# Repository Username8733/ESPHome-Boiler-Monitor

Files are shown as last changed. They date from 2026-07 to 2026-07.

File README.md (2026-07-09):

# ESPHome Boiler Monitor

Optisk pannovervakare for Home Assistant / ESPHome.

## Nya funktionsbilder

Se `docs/components/README.md` och `images/functions/`.

Varje delkrets har egen bild med exakt vilka komponentben som kopplas vart.

## GPIO

| Funktion | GPIO |
|---|---:|
| Fototransistor ADC | GPIO34 |
| Summer via 2N7000 | GPIO18 |
| Rod LED | GPIO19 |
| Gron LED | GPIO21 |
| Tyst-knapp | GPIO22 |

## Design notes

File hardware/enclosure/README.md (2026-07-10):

# Enclosure STL export

Generated from the two OpenSCAD files currently in the public repository.

## Files

- `hardware/enclosure/stl/boiler_alert_case.stl`
- `hardware/enclosure/stl/boiler_monitor_case.stl`

Each STL contains:

- Base enclosure: 100 × 60 × 30 mm
- Wall thickness: 2 mm
- Separate lid positioned 10 mm above the base in Y, matching the SCAD layout
- Lid holes:
  - Red LED: 5 mm
  - Green LED: 5 mm
  - Buzzer: 12 mm
  - Mute button: 7 mm

Triangle counts:

- boiler_alert_case.stl: 23748
- boiler_monitor_case.stl: 23748

The two SCAD files are geometrically identical except for comments.

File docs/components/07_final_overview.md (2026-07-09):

# 07 - Slutlig översikt

Schematiskt helhetsdiagram över alla funktioner tillsammans.

Bygg helst en funktion i taget med de separata funktionsbilderna.

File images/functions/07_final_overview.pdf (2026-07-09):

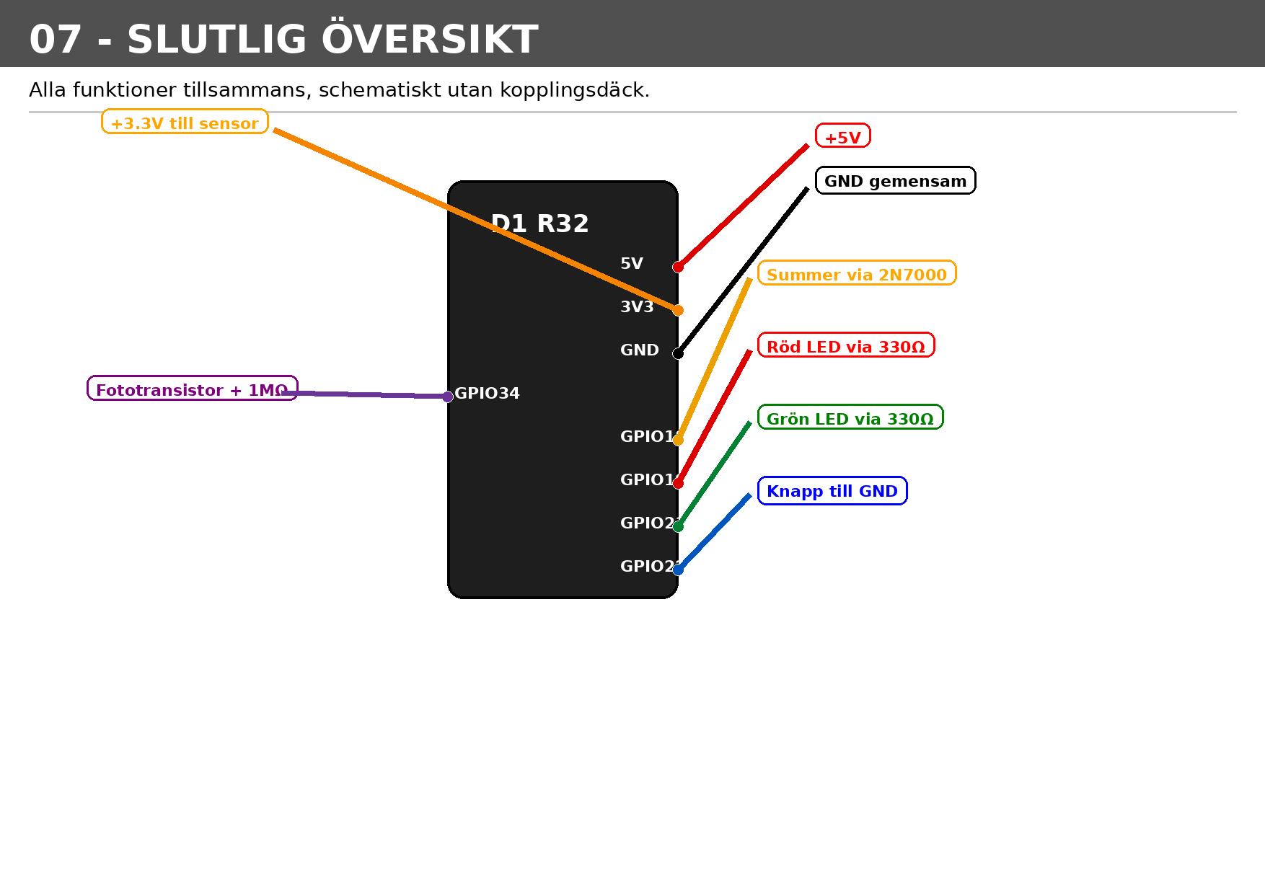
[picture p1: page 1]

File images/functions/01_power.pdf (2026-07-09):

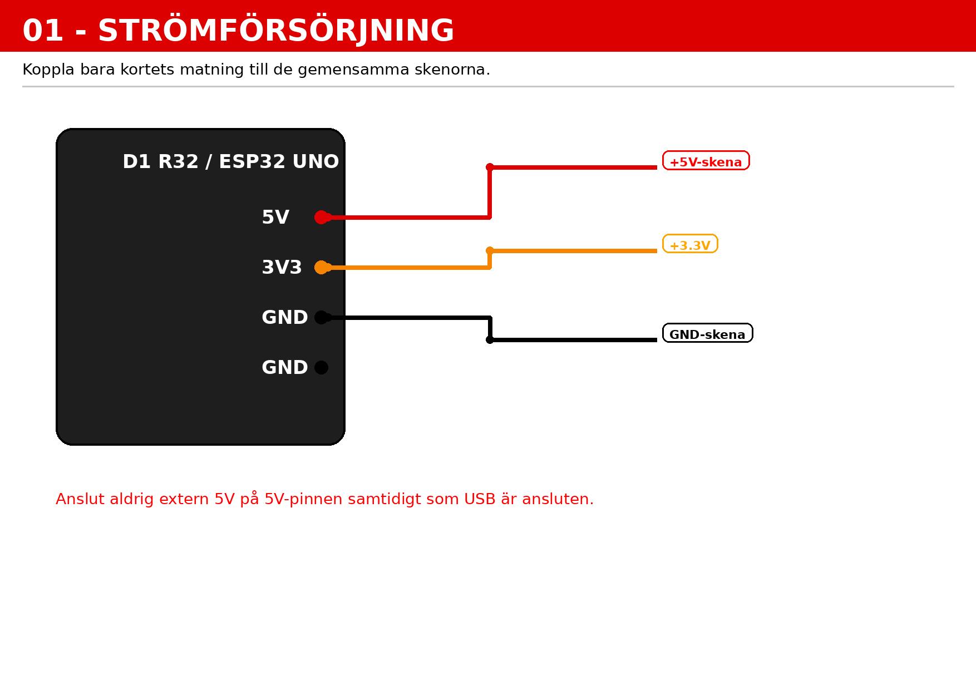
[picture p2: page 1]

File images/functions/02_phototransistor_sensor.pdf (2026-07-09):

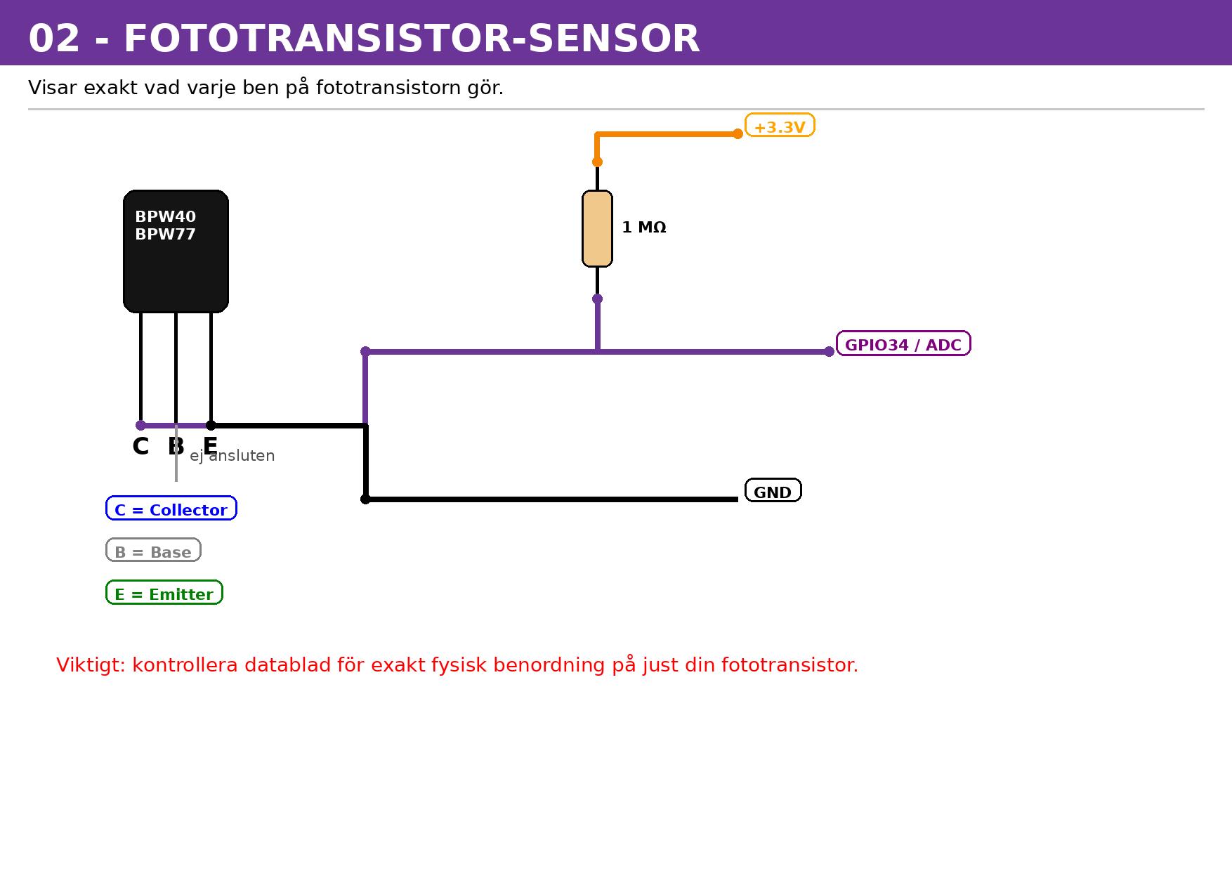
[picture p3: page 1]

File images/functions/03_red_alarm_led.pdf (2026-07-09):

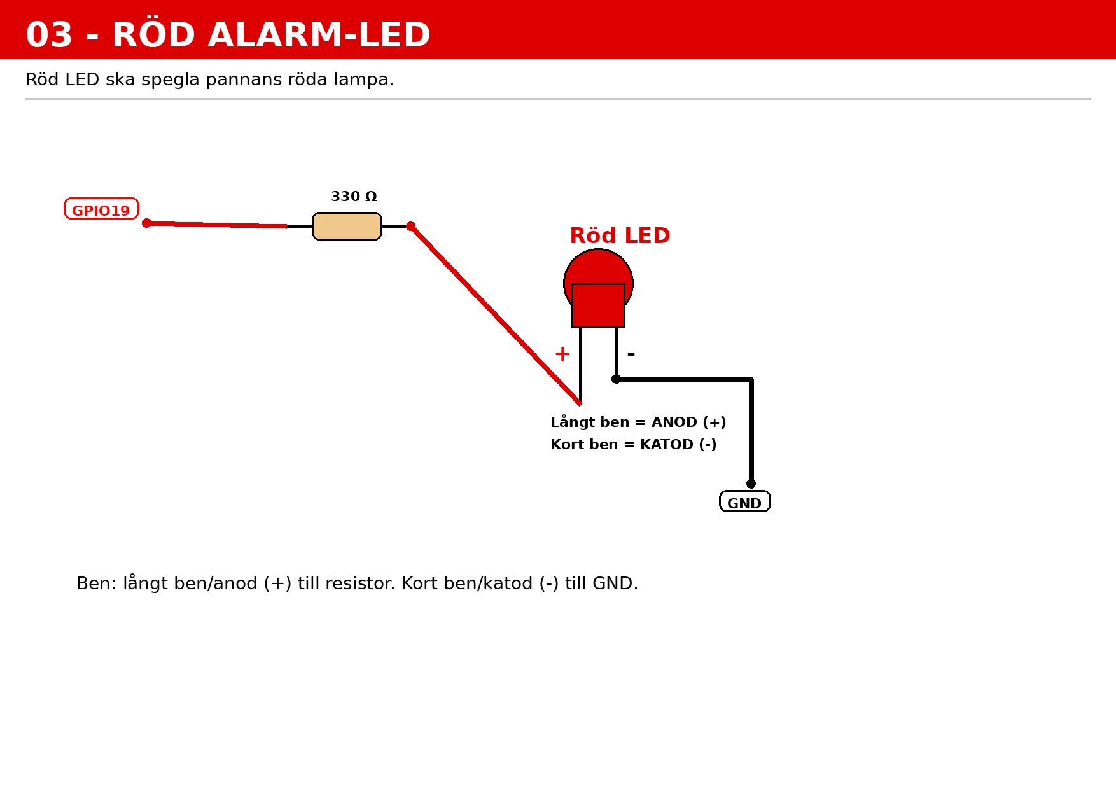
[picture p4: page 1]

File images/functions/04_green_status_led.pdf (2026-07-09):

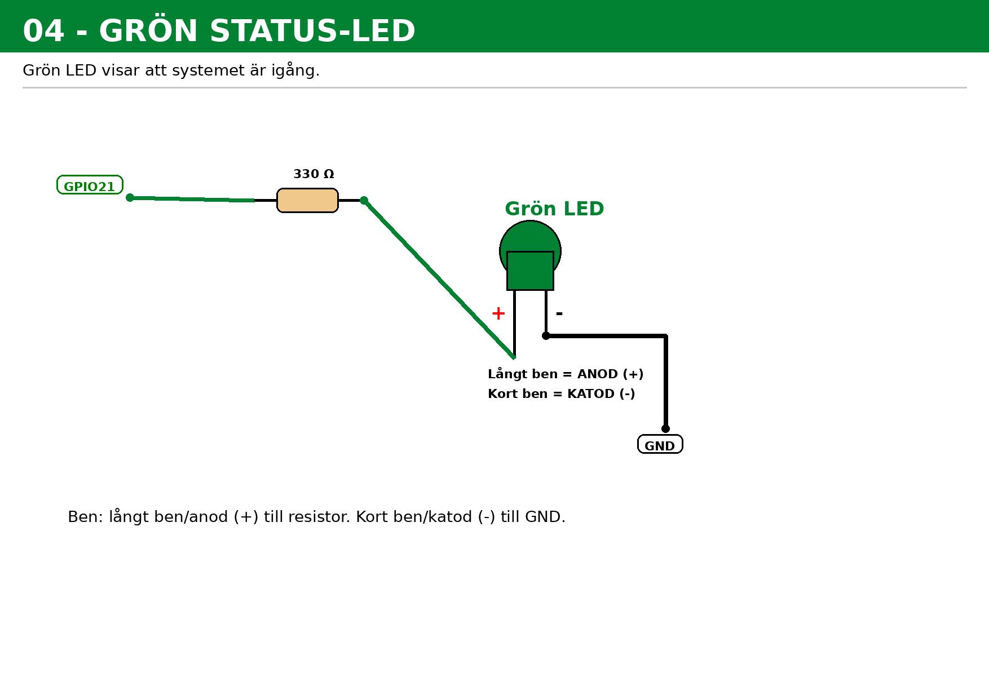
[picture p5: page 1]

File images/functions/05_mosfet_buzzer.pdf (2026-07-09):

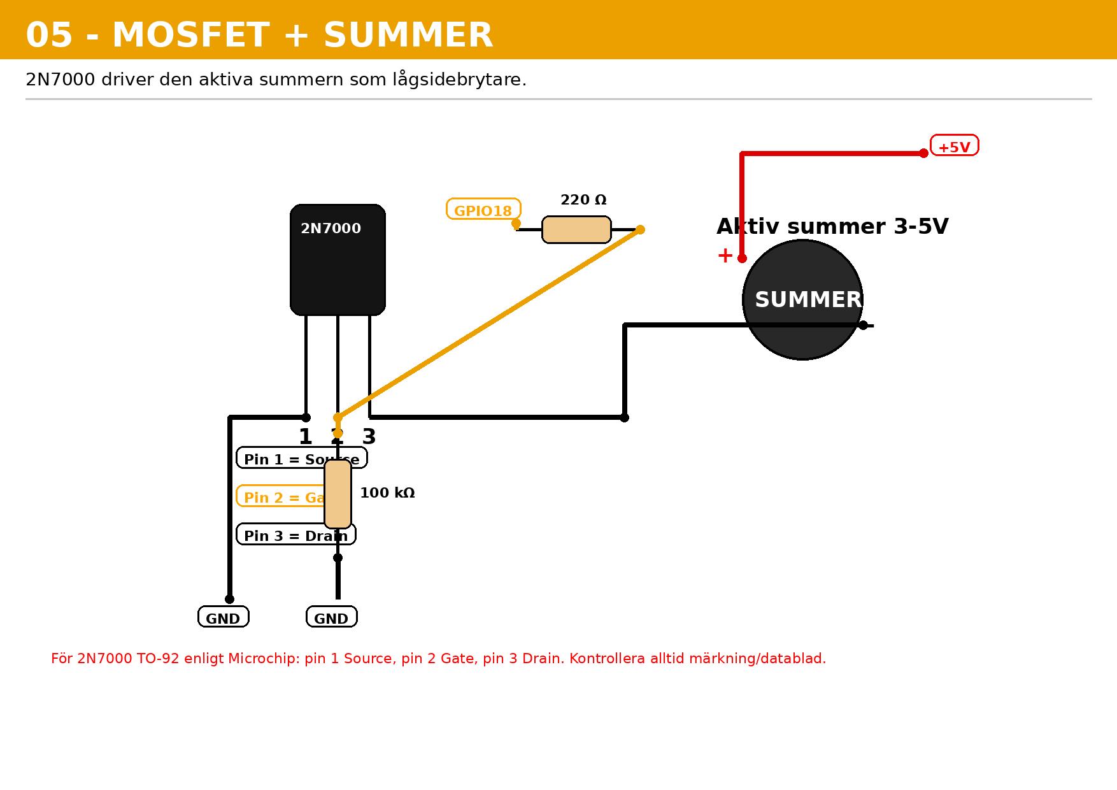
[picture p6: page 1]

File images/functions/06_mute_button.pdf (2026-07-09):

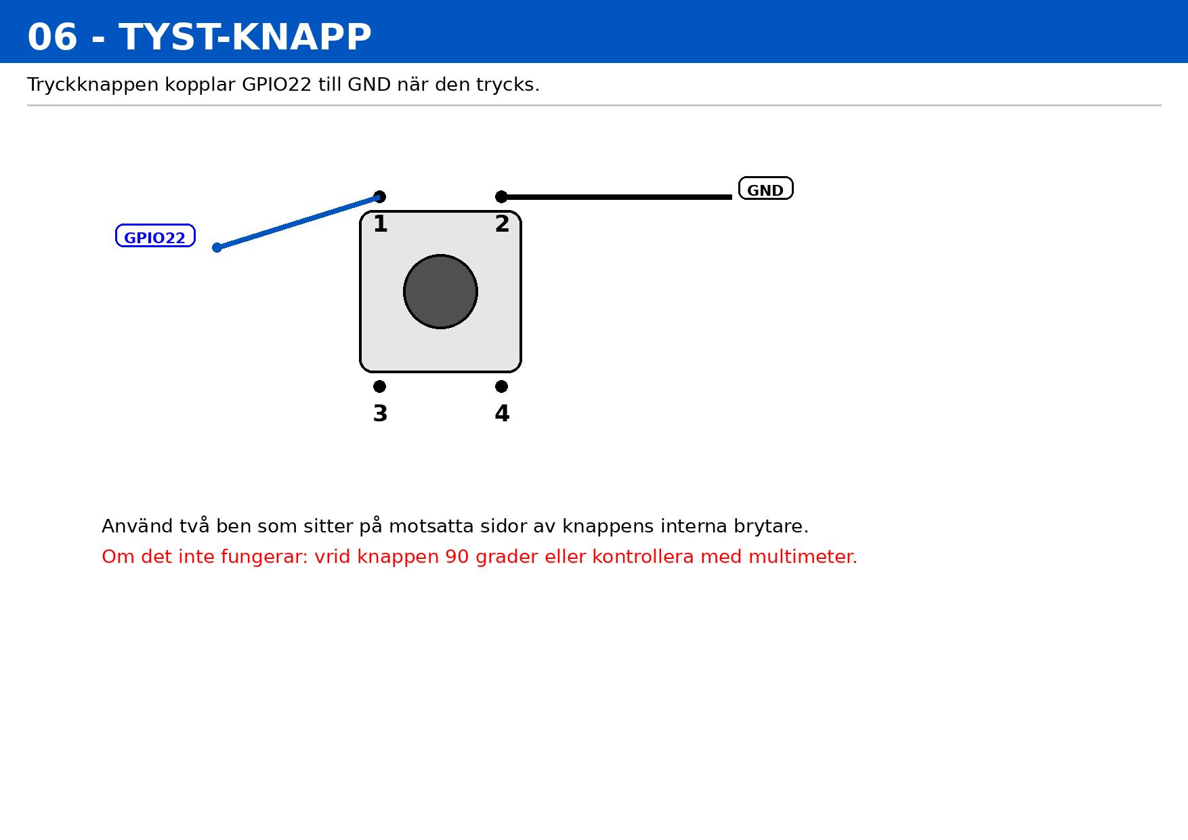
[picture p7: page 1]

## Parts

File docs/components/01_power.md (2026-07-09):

# 01 - Strömförsörjning

- D1 R32 `5V` -> +5V-skena.
- D1 R32 `3V3` -> +3.3V-nod för sensorn.
- D1 R32 `GND` -> gemensam GND-skena.

Alla GND-punkter ska vara gemensamma.

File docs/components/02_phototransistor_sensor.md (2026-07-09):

# 02 - Fototransistor-sensor

Koppling efter funktion:

- Collector `C` -> noden mellan 1 MΩ och GPIO34.
- Base `B` -> lämnas oansluten om komponenten har base-ben.
- Emitter `E` -> GND.
- 1 MΩ -> mellan +3.3V och GPIO34/sensornoden.

Kontrollera databladet för fysisk benordning på din fototransistor.

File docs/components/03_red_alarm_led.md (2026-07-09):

# 03 - Röd alarm-LED

- GPIO19 -> 330 ohm resistor.
- Resistor andra ben -> LED långt ben / anod (+).
- LED kort ben / katod (-) -> GND.

LED lyser när GPIO19 är HIGH.

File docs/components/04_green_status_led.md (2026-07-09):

# 04 - Grön status-LED

- GPIO21 -> 330 ohm resistor.
- Resistor andra ben -> LED långt ben / anod (+).
- LED kort ben / katod (-) -> GND.

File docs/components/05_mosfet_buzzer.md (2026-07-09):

# 05 - MOSFET + summer

För 2N7000 enligt Microchip TO-92:

- Pin 1 Source -> GND.
- Pin 2 Gate -> GPIO18 via 220 ohm.
- Pin 2 Gate -> GND via 100 kΩ pulldown.
- Pin 3 Drain -> summerns minus (-).
- Summerns plus (+) -> +5V.

Kontrollera alltid databladet för just din 2N7000 innan lödning.

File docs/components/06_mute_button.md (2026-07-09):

# 06 - Tyst-knapp

- Ena använda benet -> GPIO22.
- Andra använda benet -> GND.
- GPIO22 använder intern pull-up i ESPHome.

Knappens pinout varierar. Kontrollera med multimeter eller använd två ben som sluts när du trycker.

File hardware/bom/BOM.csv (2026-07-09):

Qty | Part | Value | Notes
1 | ESP32 D1 R32 | ESP32 UNO | Controller
1 | Phototransistor | BPW40/BPW77 | Sensor
1 | MOSFET | 2N7000 | Buzzer driver
1 | Active buzzer | 5V | Alarm
1 | Red LED | 5mm | Mirror
1 | Green LED | 5mm | Status
2 | Resistor | 330 ohm | LED
1 | Resistor | 220 ohm | Gate
1 | Resistor | 100k ohm | Gate pulldown
1 | Resistor | 1M ohm | Sensor pull-up

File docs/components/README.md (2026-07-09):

# Funktionsbilder

En bild per funktion. Varje bild finns som PNG och PDF.

- [01_power](../../images/functions/01_power.png) - [PDF](../../images/functions/01_power.pdf)
- [02_phototransistor_sensor](../../images/functions/02_phototransistor_sensor.png) - [PDF](../../images/functions/02_phototransistor_sensor.pdf)
- [03_red_alarm_led](../../images/functions/03_red_alarm_led.png) - [PDF](../../images/functions/03_red_alarm_led.pdf)
- [04_green_status_led](../../images/functions/04_green_status_led.png) - [PDF](../../images/functions/04_green_status_led.pdf)
- [05_mosfet_buzzer](../../images/functions/05_mosfet_buzzer.png) - [PDF](../../images/functions/05_mosfet_buzzer.pdf)
- [06_mute_button](../../images/functions/06_mute_button.png) - [PDF](../../images/functions/06_mute_button.pdf)
- [07_final_overview](../../images/functions/07_final_overview.png) - [PDF](../../images/functions/07_final_overview.pdf)

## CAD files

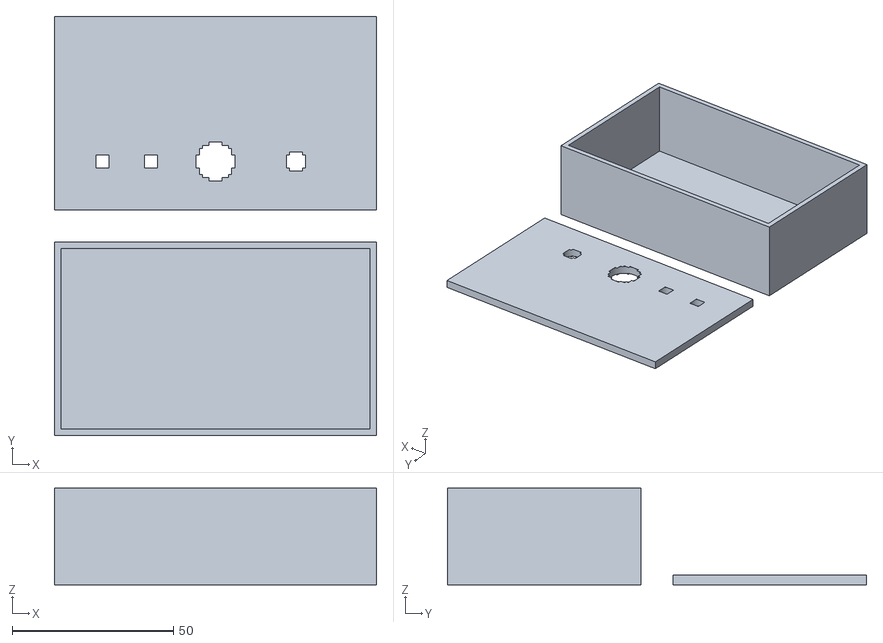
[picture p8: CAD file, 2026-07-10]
hardware/enclosure/stl/boiler_monitor_case.stl
100.0 x 130.0 x 30.0

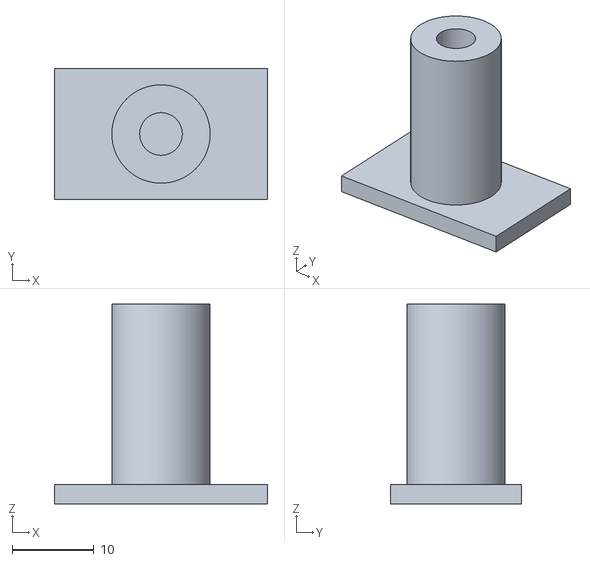
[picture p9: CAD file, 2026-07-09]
hardware/enclosure/stl/sensor_holder.stl
26.0 x 16.0 x 24.4

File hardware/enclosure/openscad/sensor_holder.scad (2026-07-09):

// ESPHome Boiler Monitor - Sensor Holder
// For BPW40/BPW77-style phototransistor in a light-shield tube.
// Print in black PETG/PLA if possible.
// Units: mm

$fn = 96;

tube_outer_d = 12;
tube_inner_d = 5.2;
tube_length  = 22;

pad_w = 26;
pad_h = 16;
pad_t = 2.4;

cable_slot_w = 3.0;
cable_slot_h = 4.0;

module sensor_tube() {
  difference() {
    cylinder(h=tube_length, d=tube_outer_d);
    translate([0,0,-0.5])
      cylinder(h=tube_length+1, d=tube_inner_d);

    // rear cable slot
    translate([-cable_slot_w/2, -tube_outer_d/2-0.2, 2])
      cube([cable_slot_w, tube_outer_d/2+1, cable_slot_h]);
  }
}

module mounting_pad() {
  translate([-pad_w/2, -pad_h/2, 0])
    cube([pad_w, pad_h, pad_t]);
}

union() {
  mounting_pad();
  translate([0,0,pad_t])
    sensor_tube();
}

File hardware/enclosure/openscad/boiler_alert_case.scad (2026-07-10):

// Boiler Alert enclosure - printable concept
$fn = 48;
box_w = 100;
box_h = 60;
box_d = 30;
wall = 2;

module base_box() {
  difference() {
    cube([box_w, box_h, box_d]);
    translate([wall, wall, wall])
      cube([box_w-2*wall, box_h-2*wall, box_d]);
  }
}

module lid() {
  difference() {
    cube([box_w, box_h, 3]);
    translate([15, 15, -1]) cylinder(h=6, d=5);   // red LED
    translate([30, 15, -1]) cylinder(h=6, d=5);   // green LED
    translate([50, 15, -1]) cylinder(h=6, d=12);  // buzzer
    translate([75, 15, -1]) cylinder(h=6, d=7);   // mute
  }
}

base_box();
translate([0, 70, 0]) lid();

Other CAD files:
hardware/enclosure/stl/boiler_alert_case.stl
hardware/enclosure/openscad/boiler_monitor_case.scad
hardware/enclosure/openscad/sensor_holder-old.scad

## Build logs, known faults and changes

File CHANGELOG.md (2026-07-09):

# Changelog

## v0.7.0

- Lagt till en utskriftsvänlig funktion-bild per delkrets.
- Lagt till PNG och PDF för varje funktion.
- Lagt till Markdown-sida per komponent/funktion.
- Förtydligat komponentben: LED anod/katod, fototransistor C/B/E, 2N7000 Source/Gate/Drain och knappben.

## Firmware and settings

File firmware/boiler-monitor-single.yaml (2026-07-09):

substitutions:
  device_name: boiler-monitor
  friendly_name: Boiler Monitor
  firmware_version: "0.8.1"

esphome:
  name: ${device_name}
  friendly_name: ${friendly_name}
  project:
    name: username8733.esphome-boiler-monitor
    version: ${firmware_version}

  on_boot:
    priority: -100
    then:
      # Enkel uppstartsindikering:
      # grön LED på, röd LED kort, kort summerpip, grön LED på.
      - output.turn_on: green_led_output
      - delay: 250ms
      - output.turn_on: red_led_output
      - delay: 250ms
      - output.turn_off: red_led_output
      - if:
          condition:
            switch.is_on: buzzer_enabled
          then:
            - output.turn_on: buzzer_output
            - delay: 120ms
            - output.turn_off: buzzer_output
      - output.turn_on: green_led_output

esp32:
  board: esp32dev
  framework:
    type: arduino

logger:

api:
  reboot_timeout: 15min

ota:
  platform: esphome

wifi:
  ssid: !secret wifi_ssid
  password: !secret wifi_password

  ap:
    ssid: "${friendly_name} Fallback"
    password: !secret fallback_ap_password

captive_portal:

web_server:
  port: 80

time:
  - platform: homeassistant
    id: ha_time

########################################################
# Outputs
########################################################

output:
  - platform: gpio
    pin: GPIO18
    id: buzzer_output

  - platform: gpio
    pin: GPIO19
    id: red_led_output

  - platform: gpio
    pin: GPIO21
    id: green_led_output

########################################################
# Diagnostic text sensors
########################################################

text_sensor:
  - platform: template
    name: "${friendly_name} Firmware Version"
    icon: mdi:tag
    entity_category: diagnostic
    lambda: |-
      return std::string("${firmware_version}");

  - platform: template
    name: "${friendly_name} Last Alarm"
    id: last_alarm_text
    icon: mdi:clock-alert
    update_interval: never

  - platform: wifi_info
    ip_address:
      name: "${friendly_name} IP Address"
      entity_category: diagnostic
    ssid:
      name: "${friendly_name} Connected SSID"
      entity_category: diagnostic
    mac_address:
      name: "${friendly_name} MAC Address"
      entity_category: diagnostic

########################################################
# Sensors
########################################################

sensor:
  # Rå ljusnivå från fototransistor
  - platform: adc
    pin: GPIO34
    id: boiler_led_level
    name: "${friendly_name} LED Level"
    attenuation: 11db
    update_interval: 100ms
    accuracy_decimals: 3
    filters:
      - exponential_moving_average:
          alpha: 0.25
          send_every: 1

  # WiFi RSSI
  - platform: wifi_signal
    id: wifi_rssi
    name: "${friendly_name} WiFi Signal"
    update_interval: 60s
    entity_category: diagnostic

  # WiFi kvalitet i procent
  - platform: copy
    source_id: wifi_rssi
    name: "${friendly_name} WiFi Signal Percent"
    unit_of_measurement: "%"
    entity_category: diagnostic
    filters:
      - lambda: |-
          if (x <= -100.0) return 0.0;
          if (x >= -50.0) return 100.0;
          return 2.0 * (x + 100.0);

  # Uptime
  - platform: uptime
    name: "${friendly_name} Uptime"
    update_interval: 60s
    entity_category: diagnostic

  # DS18B20 temperaturgivare
  # Koppling:
  # VDD  -> 3V3
  # GND  -> GND
  # DATA -> GPIO23
  # 4.7k mellan DATA och 3V3
  - platform: dallas_temp
    name: "${friendly_name} Temperature"
    id: boiler_temperature
    update_interval: 30s
    accuracy_decimals: 1

########################################################
# 1-Wire bus for DS18B20
########################################################

one_wire:
  - platform: gpio
    pin: GPIO23
    id: one_wire_bus

########################################################
# Adjustable settings
########################################################

number:
  - platform: template
    id: boiler_led_threshold
    name: "${friendly_name} LED Threshold"
    optimistic: true
    restore_value: true
    initial_value: 1.20
    min_value: 0.05
    max_value: 3.10
    step: 0.05
    unit_of_measurement: "V"

  - platform: template
    id: alarm_clear_delay_seconds
    name: "${friendly_name} Alarm Clear Delay"
    optimistic: true
    restore_value: true
    initial_value: 0
    min_value: 0
    max_value: 600
    step: 10
    unit_of_measurement: "s"

########################################################
# Globals
########################################################

globals:
  - id: alarm_latched
    type: bool
    restore_value: no
    initial_value: 'false'

  - id: alarm_muted
    type: bool
    restore_value: no
    initial_value: 'false'

  - id: buzzer_phase
    type: bool
    restore_value: no
    initial_value: 'false'

  - id: last_alarm_seen_ms
    type: uint32_t
    restore_value: no
    initial_value: '0'
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

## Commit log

2026-07-09 v 0.7.0
    [BOM.csv]
2026-07-09 v 0.8.1
    [sensor_holder-old.scad, sensor_holder.scad, sensor_holder.stl]
